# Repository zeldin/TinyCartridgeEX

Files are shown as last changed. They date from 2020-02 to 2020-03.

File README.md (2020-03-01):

WARNING
=======

This design is completely untested.  Since the TinyFPGA EX is not
actually available yet, there are also a number of open questions
such as:

* Does the width of the module match a standard DIL-48 socket?
  - Yes it does

* Is it OK to power the module by feeding +5V into the `Vin` pin,
  and use the `3v3` pin(s) to power auxilliary logic?  (I would
  assume so, but needs to be verified.)
  - Seems legit.  The DC/DC for 3.3V works with input voltage down
    to 3.8V, so add a protection diode with Vf < 1V.

* Are all the 42 numbered pins capable of 3.3V I/O (I sure hope so)?
  - Accoring to published schematics, VCCIO0-2 and VCCIO6-8 are all tied
  to 3.3V, which should cover all 42 pins.

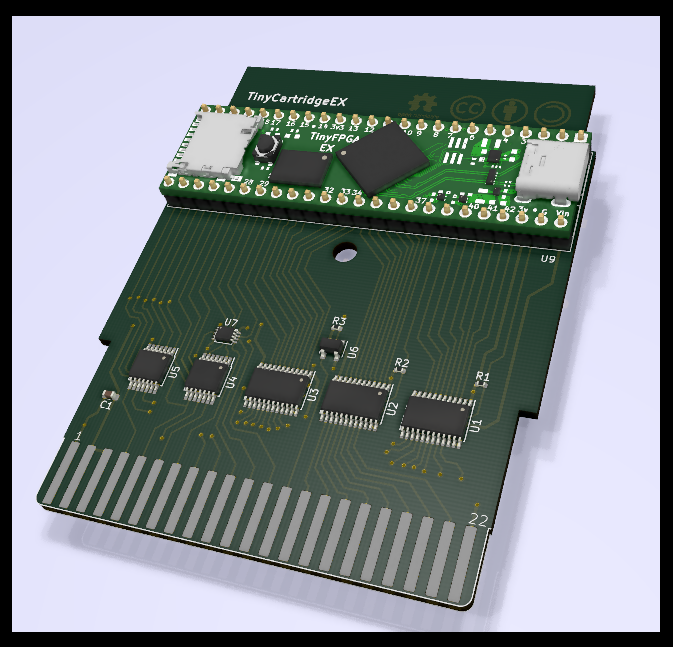
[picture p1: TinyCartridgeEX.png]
Board render


TinyCartridge EX
================

The TinyCartridge EX is a carrier board for the upcoming
[TinyFPGA EX](https://www.crowdsupply.com/tinyfpga/tinyfpga-ex)
FPGA module in the form of a Commodore 64 cartridge.  All pins
on the C64 expansion port are directly available to the FPGA, with
the modification that `IO1` and `IO2` are reduced to a single
signal with NAND, and the same for `ROML` and `ROMH`.

The intention is to provide a platform for the
[super-reu](https://github.com/zeldin/super-reu) supported by
open toolchains (i.e. SymbiFlow).

Acknowledgements
----------------

The C64 expansion port and cartridge symbol and footprint were
designed by [RETRO Innovations](http://www.go4retro.com/).

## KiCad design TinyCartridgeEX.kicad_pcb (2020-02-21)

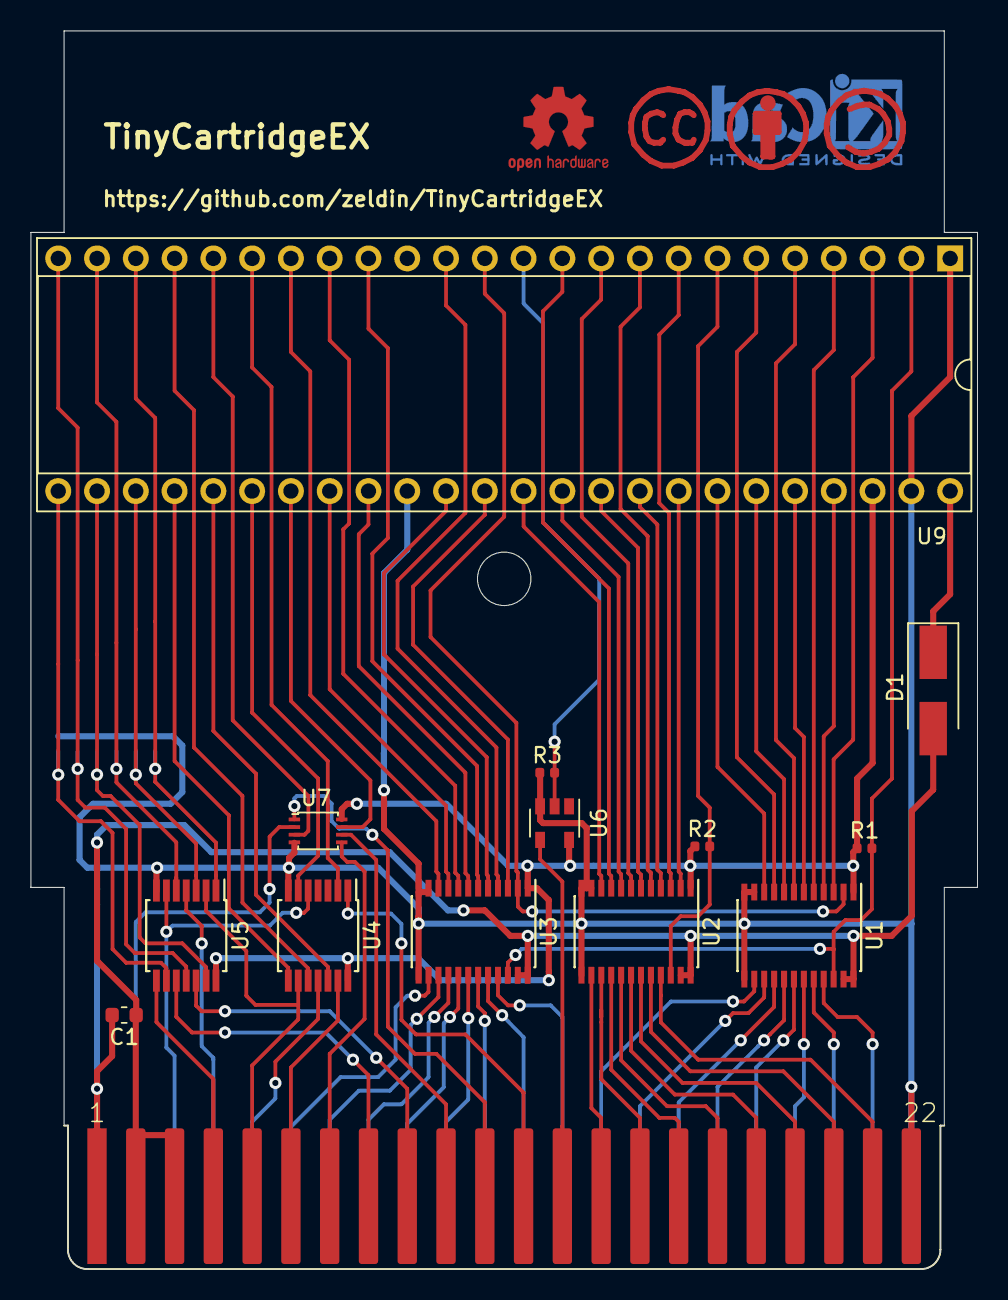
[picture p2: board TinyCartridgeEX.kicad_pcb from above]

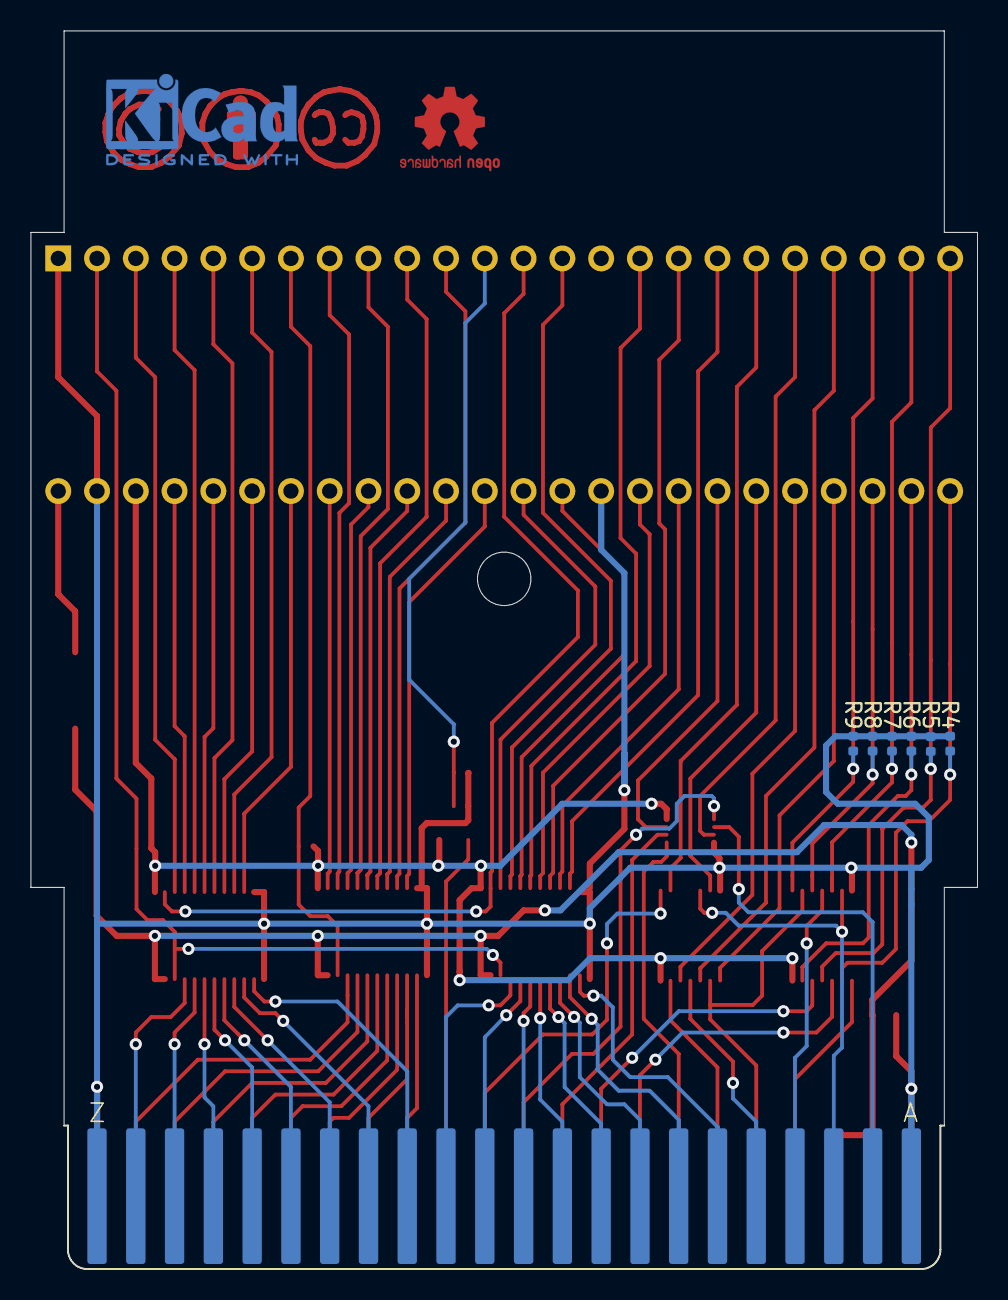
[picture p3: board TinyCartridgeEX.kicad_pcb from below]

Board: 2 copper layers, 62.0 x 81.1 mm, 28 parts (7 on the bottom side), 84 nets.

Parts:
C1: 0.1u; C_0603_1608Metric
CART1: CARTRIDGE_C64; CARTRIDGE_C64_GERMAN
D1: EC30QSA045; D_SMA_Handsoldering
J1, J2: Conn_01x24; PinHeader_1x24_P2.54mm_Vertical_UpsideDown
R1, R2, R3, R4, R5, R6, R7, R8, R9: 4.7k; R_0402_1005Metric
REFBY: Symbol_CC-Attribution_CopperTop_Small
REFCC: Symbol_CreativeCommons_CopperTop_Type2_Small
REFKI: KiCad-Logo2_5mm_Copper
REFOSHW: OSHW-Logo2_7.3x6mm_Copper
REFSA: Symbol_CC-ShareAlike_CopperTop_Small
U1, U2, U3: SN74LVC8T245; TSSOP-24_4.4x7.8mm_P0.65mm
U4: 74LV17A; TSSOP-14_4.4x5mm_P0.65mm
U5: 74LVC06A; TSSOP-14_4.4x5mm_P0.65mm
U6: 74LVC1G06; SOT-23-5
U7: 74LVC2G132; VSSOP-8_2.4x2.1mm_P0.5mm
U9: TinyFPGA_EX
X1: EXPANSION_PORT_C64_EDGE; MA100-22-2

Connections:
+5V: C1.1, D1.2, U1.23, U1.24, U2.23, U2.24, U3.23, U3.24, X1.2, X1.3
/Level Shifters/8: U3.21, X1.P
/Level Shifters/9: U3.20, X1.N
/Level Shifters/10: U3.19, X1.M
/Level Shifters/11: U3.18, X1.L
/Level Shifters/12: U3.17, X1.K
/Level Shifters/13: U3.16, X1.J
/Level Shifters/14: U3.15, X1.H
/Level Shifters/15: U3.14, X1.F
A0: U1.3, U9.3
A1: U1.4, U9.45
A2: U1.5, U9.4
A3: U1.6, U9.44
A4: U1.7, U9.5
A5: U1.8, U9.43
A6: U1.9, U9.6
A7: U1.10, U9.42
A8: U3.3, U9.36
A9: U3.4, U9.14
A10: U3.5, U9.35
A11: U3.6, U9.16
A12: U3.7, U9.33
A13: U3.8, U9.17
A14: U3.9, U9.32
A15: U3.10, U9.18
A_DIR: U1.2, U3.2, U9.13
A_~EN: R1.2, U1.22, U3.22, U9.2
BA: U4.2, U9.19
D0: U2.3, U9.8
D1: U2.4, U9.40
D2: U2.5, U9.9
D3: U2.6, U9.39
D4: U2.7, U9.10
D5: U2.8, U9.38
D6: U2.9, U9.11
D7: U2.10, U9.37
DMA: R3.1, U6.2, U9.12
DOTCLK: U4.12, U9.29
D_DIR: U2.2, U9.41
D_~EN: R2.1, U2.22, U9.7
EXROM: R6.1, U5.13, U9.26
GAME: R5.1, U5.11, U9.24
GND: C1.2, R3.2, R4.2, R5.2, R6.2, R7.2, R8.2, R9.2, U1.11, U1.12, U1.13, U2.11, U2.12, U2.13, U3.11, U3.12, U3.13, U4.7, U5.7, U6.3, U7.4, U9.1, U9.34, U9.47, X1.1, X1.22, X1.A, X1.Z
IO12: U7.3, U9.20
IRQ_OUT: R4.1, U5.9, U9.25
NMI_OUT: R8.1, U5.3, U9.27
unnamed: D1.1, U9.48
unnamed: U1.14, X1.R
unnamed: U1.15, X1.S
unnamed: U1.16, X1.T
unnamed: U1.17, X1.U
unnamed: U1.18, X1.V
unnamed: U1.19, X1.W
unnamed: U1.20, X1.X
unnamed: U1.21, X1.Y
unnamed: U2.14, X1.14
unnamed: U2.15, X1.15
unnamed: U2.16, X1.16
unnamed: U2.17, X1.17
unnamed: U2.18, X1.18
unnamed: U2.19, X1.19
unnamed: U2.20, X1.20
unnamed: U2.21, X1.21
unnamed: U4.1, X1.12
unnamed: U4.5, U5.6, X1.C
unnamed: U4.9, U5.2, X1.5
unnamed: U4.11, X1.E
unnamed: U4.13, X1.6
unnamed: U5.4, X1.D
unnamed: U5.8, X1.4
unnamed: U5.10, X1.8
unnamed: U5.12, X1.9
unnamed: U6.4, X1.13
unnamed: U7.1, X1.11
unnamed: U7.2, X1.B
unnamed: U7.5, X1.7
unnamed: U7.6, X1.10
PHI2: U4.10, U9.21
RESET_IN: U4.6, U9.30
RESET_OUT: R7.1, U5.5, U9.23
ROMLH: U7.7, U9.31
RW_IN: U4.8, U9.28
RW_OUT: R9.1, U5.1, U9.22
VCC: R1.1, R2.2, U1.1, U2.1, U3.1, U4.14, U5.14, U6.5, U7.8, U9.46

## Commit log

2020-02-09 Remove superfluous Schmitt buffers on NAND inputs
    [FPGA.sch, TinyCartridgeEX.kicad_pcb, TinyCartridgeEX.sch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]
2020-02-09 Set correct logic families and add Mouser part# and pricing for BOM
    [FPGA.sch, TinyCartridgeEX.kicad_pcb, TinyCartridgeEX.sch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]
2020-02-09 Slightly cleanup schematic page
    [level_shifters.sch]
2020-02-09 Remove funky drill hole from cartridge footprint
2020-02-09 Fix PCB outline and add some logos/text
    [TinyCartridgeEX.kicad_pcb]
2020-02-10 Move SN74AVC8T245PW symbol into buffers.lib
    It turns out some version of Logic_LevelTranslator.lib doesn't have
    it.
    [level_shifters.sch]
2020-02-11 Replace cartridge footprint
    The new footprint is created based on the technical drawings
    found here: http://wiki.icomp.de/wiki/C64_Cartridge_Cases
    [TinyCartridgeEX.kicad_pcb, level_shifters.sch]
2020-02-19 Insert a 3D model of the TinyFPGA EX module
    [FPGA.sch, TinyCartridgeEX.kicad_pcb]
2020-02-20 Add diode to Vin
    [FPGA.sch, TinyCartridgeEX.kicad_pcb]
2020-02-21 Fix badly placed trace
    [TinyCartridgeEX.kicad_pcb]
2020-03-01 BOM update
    [FPGA.sch, level_shifters.sch]
